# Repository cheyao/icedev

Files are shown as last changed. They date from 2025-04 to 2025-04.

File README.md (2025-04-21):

# Icedev

A ICE40 FPGA breakout board. With built in clock, voltage regs, ram and rom.

- 64 KiB of onboard flash
- 128 MiB of NOR flash
- 16 MHZ onboard Crystal
- 256 KiB of built-in RAM




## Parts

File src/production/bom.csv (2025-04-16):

Designator | Footprint | Quantity | Value | LCSC Part #
5V, C1, C10, C13, C15, C16, C18, C2, C21, C23, C3, C4, C8 | 0402 | 13 | 0.1u | C1525
C12, C14, C17, C19 | 0402 | 4 | 10u | C15525
C20, C5, C6, C7, C9 | 0402 | 5 | 10n | C15195
D1 | D_SOD-123 | 1 | Schottky Diode | C8598
D2, D4 | 0805 | 2 | G | C2297
D3 | 0603 | 1 | R | C2286
GND_3, R26 | 0805 | 2 | 5.1K | C27834
R19, R22, R23, R24, R25 | 0805 | 5 | 1K | C17513
R20, R21 | 0402 | 2 | 5.1K | C25905
R6, R7, R8, R9 | 0805 | 4 | 10K | C17414
U1 | QFN-48-1EP_7x7mm_P0.5mm_EP5.6x5.6mm | 1 | ICE40UP5K-SG48ITR | C2678152
U2 | SOT-223-3_TabPin2 | 1 | AMS1117-1.2 | C14529
U3 | SOT-223-3_TabPin2 | 1 | AMS1117-3.3 | C6186
U4 | SOIC-8_5.3x5.3mm_P1.27mm | 1 | W25Q128JVS | C97521
U5 | SOIC-8_3.9x4.9mm_P1.27mm | 1 | FM24C64B | C79988
U6 | SOT-23-6-routable | 1 | SRV05-4 | C85364
X1 | Oscillator_SMD_Abracon_ASE-4Pin_3.2x2.5mm | 1 | MPUOSC | C13738

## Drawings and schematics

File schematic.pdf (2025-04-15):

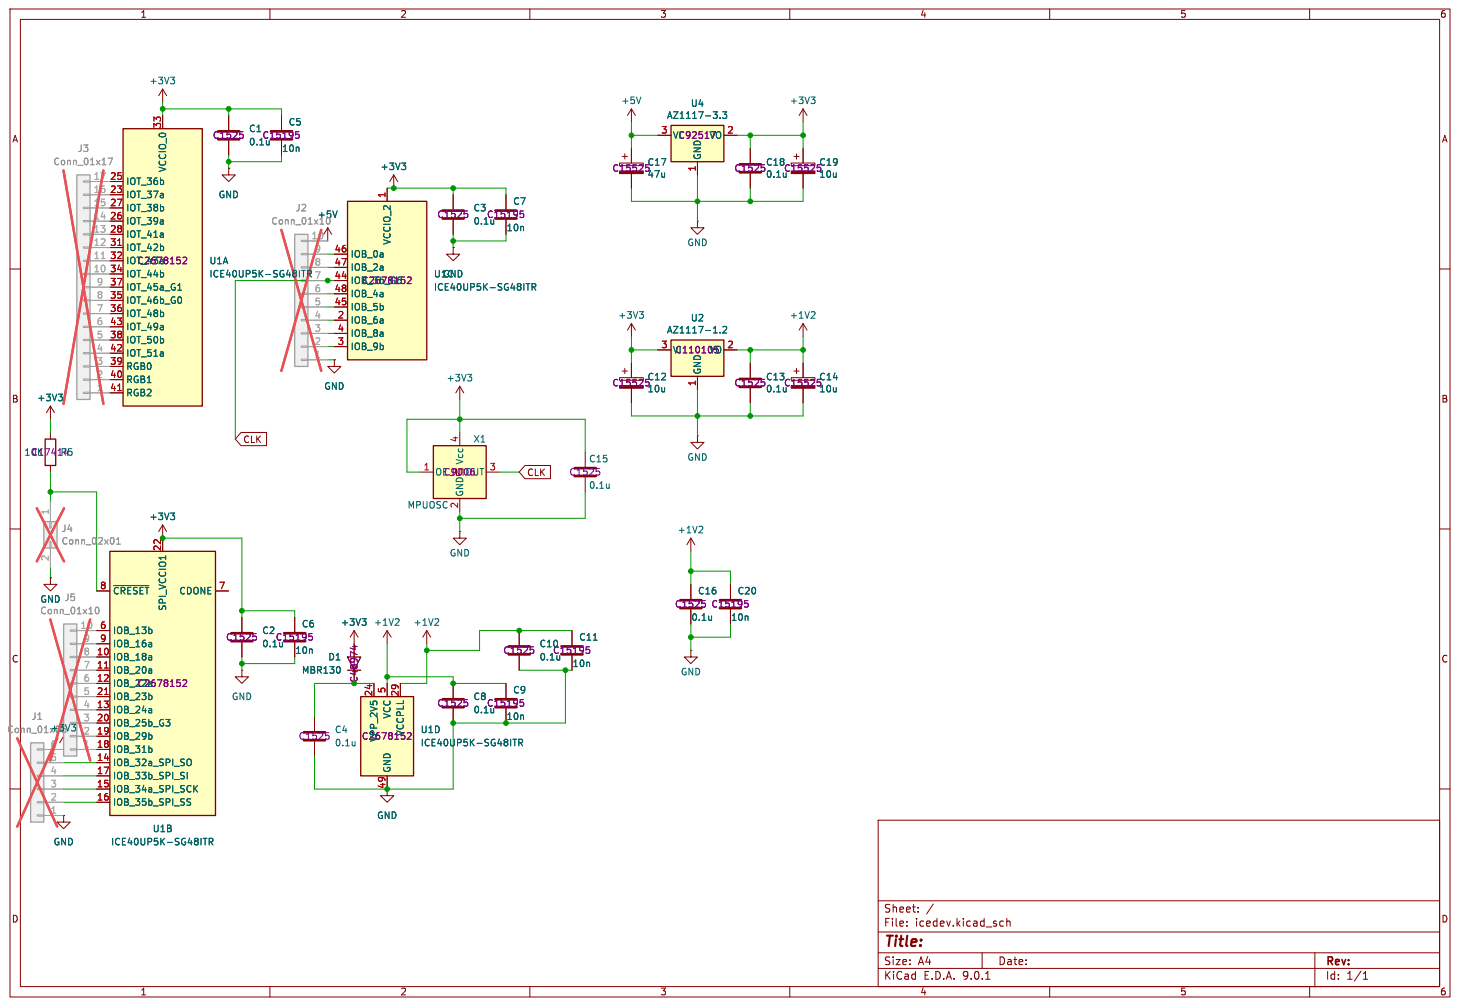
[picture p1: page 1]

Id: 1/1 Title: File: icedev.kicad_sch Sheet: /

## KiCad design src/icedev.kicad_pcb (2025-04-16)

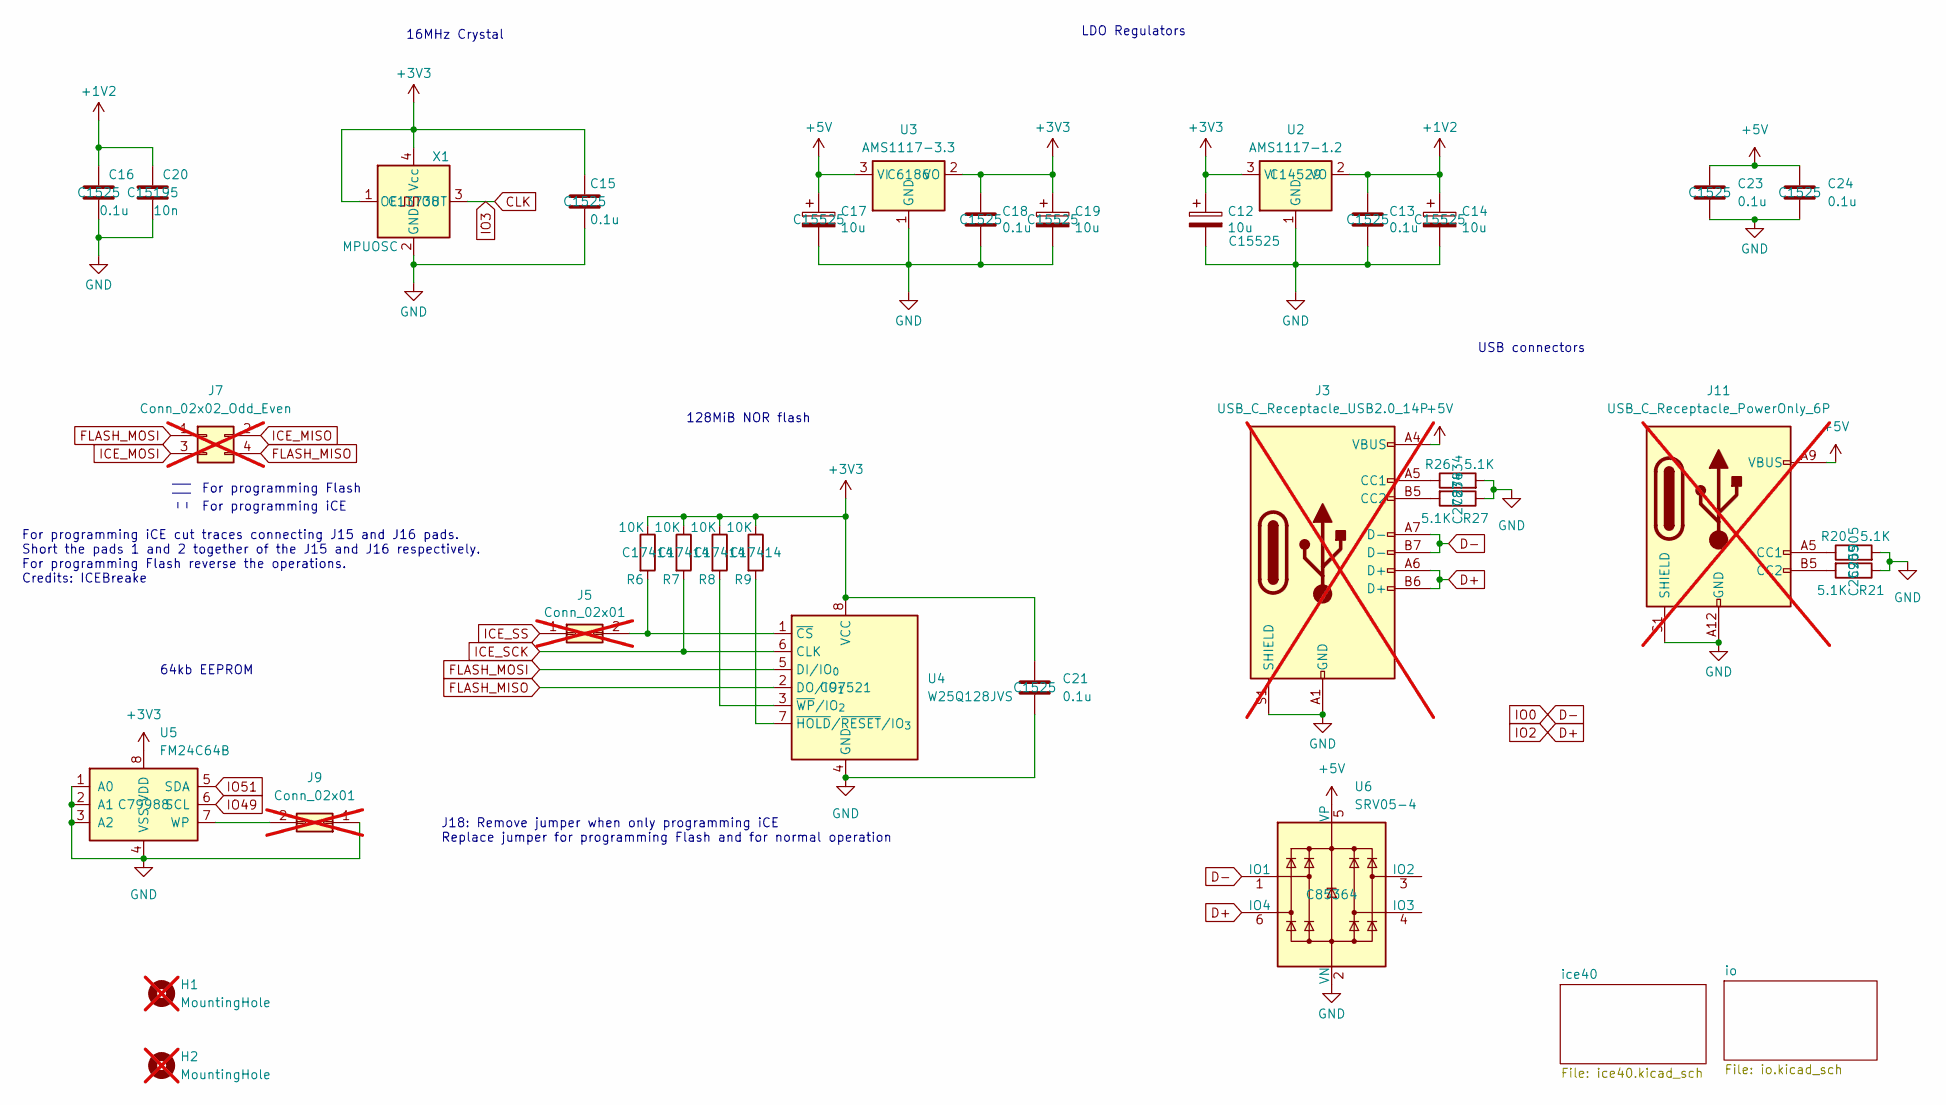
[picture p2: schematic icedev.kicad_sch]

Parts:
C12, C14, C17, C19: 10u; C_0402_1005Metric; JLCPCB Part # C15525
C13, C15, C16, C18, C21, C23, C24: 0.1u; C_0402_1005Metric; JLCPCB Part # C1525
C20: 10n; C_0402_1005Metric; JLCPCB Part # C15195
H1, H2: MountingHole; MountingHole_2.2mm_M2; not fitted
J3: USB_C_Receptacle_USB2.0_14P; USB_C_Receptacle_GCT_USB4105-xx-A_16P_TopMnt_Horizontal; not fitted
J5, J9: Conn_02x01; PinHeader_2x01_P2.54mm_Vertical; not fitted
J7: Conn_02x02_Odd_Even; PinSocket_2x02_P2.54mm_Vertical; not fitted
J11: USB_C_Receptacle_PowerOnly_6P; USB_C_Receptacle_GCT_USB4135-GF-A_6P_TopMnt_Horizontal; not fitted
R6, R7, R8, R9: 10K; R_0805_2012Metric; JLCPCB Part # C17414
R20, R21: 5.1K; R_0402_1005Metric; JLCPCB Part # C25905
R26, R27: 5.1K; R_0805_2012Metric; JLCPCB Part # C27834
U2: AMS1117-1.2; SOT-223-3_TabPin2; JLCPCB Part # C14529
U3: AMS1117-3.3; SOT-223-3_TabPin2; JLCPCB Part # C6186
U4: W25Q128JVS; SOIC-8_5.3x5.3mm_P1.27mm; JLCPCB Part # C97521
U5: FM24C64B; SOIC-8_3.9x4.9mm_P1.27mm; JLCPCB Part # C79988
U6: SRV05-4; SOT-23-6-routable; JLCPCB Part # C85364
X1: MPUOSC; Oscillator_SMD_Abracon_ASE-4Pin_3.2x2.5mm; JLCPCB Part # C13738

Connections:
+1V2: C13.1, C14.1, C16.1, C20.1, U2.2 (VO); also elsewhere on the board
+3V3: C12.1, C15.1, C18.1, C19.1, C21.1, R6.1, R7.1, R8.1, R9.1, U2.3 (VI), U3.2 (VO), U4.8 (VCC), U5.8 (VDD), X1.1 (OE), X1.4 (Vcc); also elsewhere on the board
+5V: C17.1, C23.1, C24.1, J3.A4 (VBUS), J3.A9 (VBUS), J3.B4 (VBUS), J3.B9 (VBUS), J11.A9 (VBUS), J11.B9 (VBUS), U3.3 (VI), U6.5 (VP); also elsewhere on the board
CLK: X1.3 (OUT); also elsewhere on the board
D+: J3.A6 (D+), J3.B6 (D+), U6.6 (IO4); also elsewhere on the board
D-: J3.A7 (D-), J3.B7 (D-), U6.1 (IO1); also elsewhere on the board
FLASH_MISO: J7.4, U4.2 (DO/IO_{1}); also elsewhere on the board
FLASH_MOSI: J7.1, U4.5 (DI/IO_{0}); also elsewhere on the board
GND: C12.2, C13.2, C14.2, C15.2, C16.2, C17.2, C18.2, C19.2, C20.2, C21.2, C23.2, C24.2, J3.A1 (GND), J3.A12 (GND), J3.B1 (GND), J3.B12 (GND), J3.S1 (SHIELD), J9.1, J11.A12 (GND), J11.B12 (GND), J11.S1 (SHIELD), R20.2, R21.1, R26.2, R27.1, U2.1 (GND), U3.1 (GND), U4.4 (GND), U5.1 (A0), U5.2 (A1), U5.3 (A2), U5.4 (VSS), U6.2 (VN), X1.2 (GND); also elsewhere on the board
ICE_MISO: J7.2; also elsewhere on the board
ICE_MOSI: J7.3; also elsewhere on the board
ICE_SCK: R7.2, U4.6 (CLK); also elsewhere on the board
ICE_SS: J5.1; also elsewhere on the board
IO49: U5.6 (SCL); also elsewhere on the board
IO51: U5.5 (SDA); also elsewhere on the board
unnamed: J3.A5 (CC1), R26.1
unnamed 52: J3.B5 (CC2), R27.2; also elsewhere on the board
unnamed: J5.2, R6.2, U4.1 (~CS)
unnamed: J9.2, U5.7 (WP)
unnamed: J11.A5 (CC1), R20.1
unnamed: J11.B5 (CC2), R21.2
unnamed: R9.2, U4.7 (~HOLD/~RESET/IO_{3})
unnamed: R8.2, U4.3 (~WP/IO_{2})

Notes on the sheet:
For programming Flash
J18: Remove jumper when only programming iCE Replace jumper for programming Flash and for normal operation
64kb EEPROM
16MHz Crystal
USB connectors
For programming iCE cut traces connecting J15 and J16 pads. Short the pads 1 and 2 together of the J15 and J16 respectively. For programming Flash reverse the operations. Credits: ICEBreake
128MiB NOR flash
LDO Regulators
For programming iCE

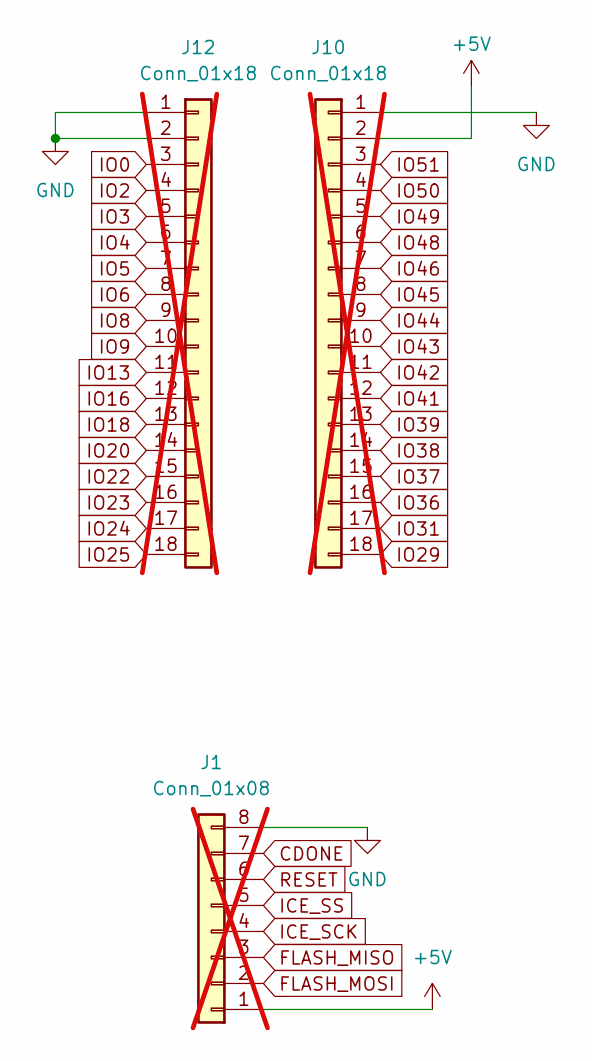
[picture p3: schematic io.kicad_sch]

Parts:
J1: Conn_01x08; PinSocket_1x08_P2.54mm_Vertical; not fitted
J10, J12: Conn_01x18; PinSocket_1x18_P2.54mm_Vertical; not fitted

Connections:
+5V: J1.1, J10.2; also elsewhere on the board
CDONE: J1.7; also elsewhere on the board
FLASH_MISO: J1.3; also elsewhere on the board
FLASH_MOSI: J1.2; also elsewhere on the board
GND: J1.8, J10.1, J12.1, J12.2; also elsewhere on the board
ICE_SCK: J1.4; also elsewhere on the board
ICE_SS: J1.5; also elsewhere on the board
RESET: J1.6; also elsewhere on the board

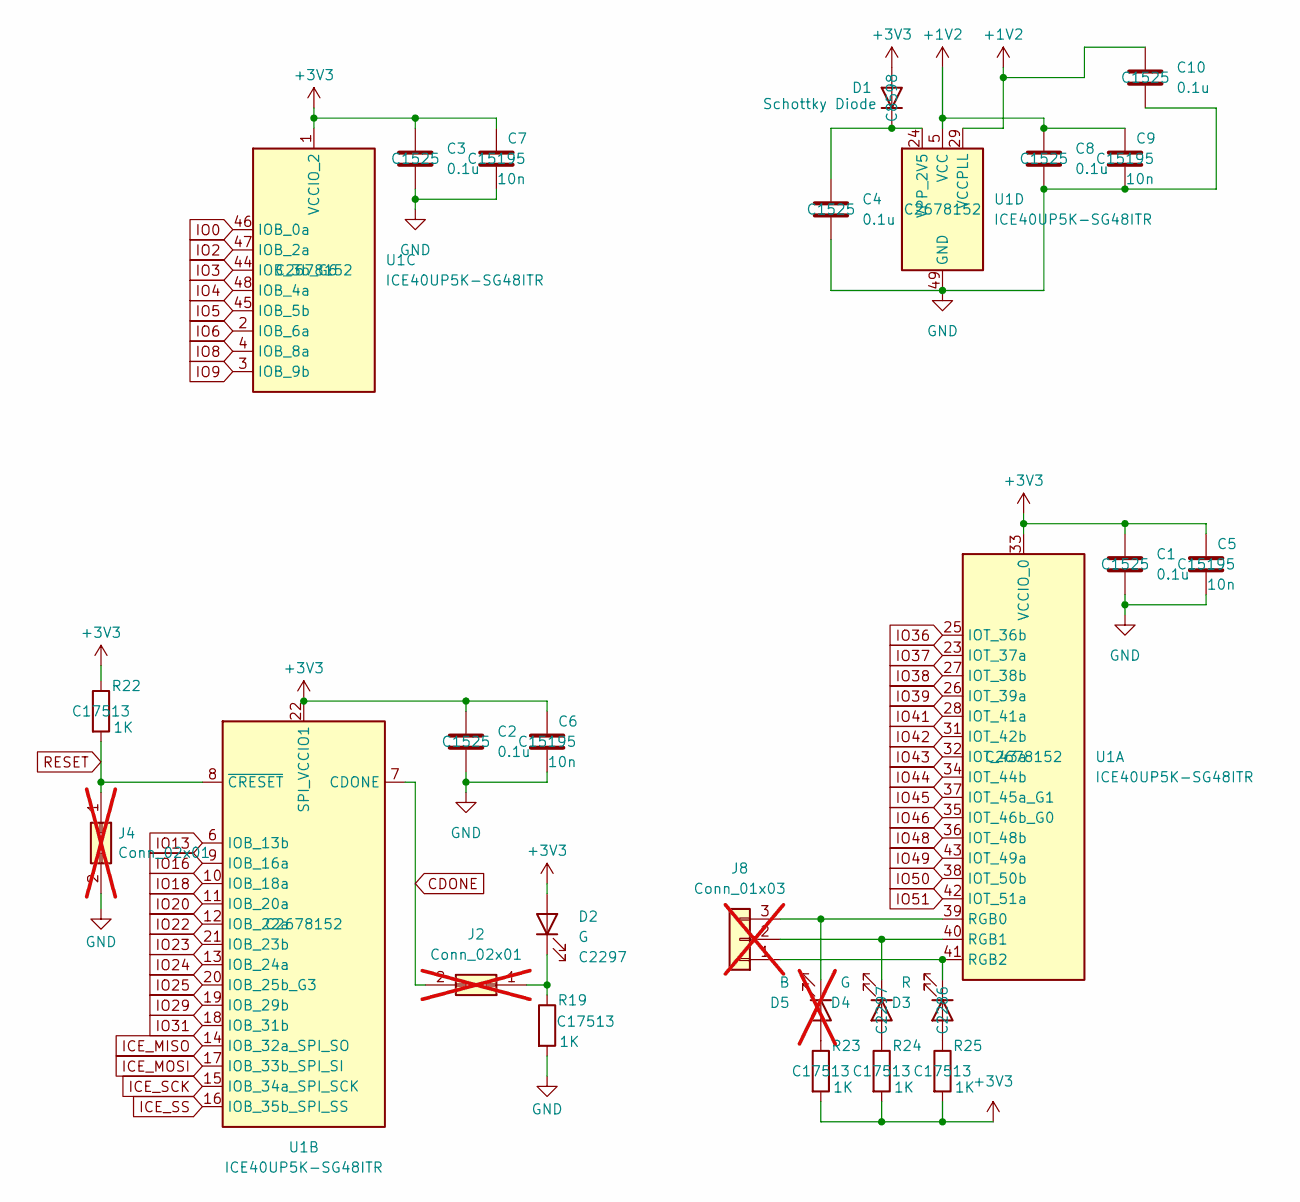
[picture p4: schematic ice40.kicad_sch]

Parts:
C1, C2, C3, C4, C8, C10: 0.1u; C_0402_1005Metric; JLCPCB Part # C1525
C5, C6, C7, C9: 10n; C_0402_1005Metric; JLCPCB Part # C15195
D1: Schottky Diode; D_SOD-123; JLCPCB Part # C8598
D2, D4: G; LED_0805_2012Metric; JLCPCB Part # C2297
D3: R; LED_0603_1608Metric; JLCPCB Part # C2286
D5: B; LED_0201_0603Metric_Pad0.64x0.40mm_HandSolder; not fitted
J2, J4: Conn_02x01; PinHeader_2x01_P2.54mm_Vertical; not fitted
J8: Conn_01x03; PinHeader_1x03_P2.54mm_Vertical; not fitted
R19, R22, R23, R24, R25: 1K; R_0805_2012Metric; JLCPCB Part # C17513
U1: ICE40UP5K-SG48ITR; QFN-48-1EP_7x7mm_P0.5mm_EP5.6x5.6mm; JLCPCB Part # C2678152

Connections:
+1V2: C8.1, C9.1, C10.1, U1.5 (VCC), U1.29 (VCCPLL), U1.30 (VCC); also elsewhere on the board
+3V3: C1.1, C2.1, C3.1, C5.1, C6.1, C7.1, D1.2 (A), D2.2 (A), R22.1, R23.2, R24.2, R25.2, U1.1 (VCCIO_2), U1.22 (SPI_VCCIO1), U1.33 (VCCIO_0); also elsewhere on the board
CDONE: J2.2, U1.7 (CDONE); also elsewhere on the board
CLK: U1.44 (IOB_3b_G6); also elsewhere on the board
D+: U1.47 (IOB_2a); also elsewhere on the board
D-: U1.46 (IOB_0a); also elsewhere on the board
GND: C1.2, C2.2, C3.2, C4.2, C5.2, C6.2, C7.2, C8.2, C9.2, C10.2, J4.2, R19.2, U1.49 (GND); also elsewhere on the board
ICE_MISO: U1.14 (IOB_32a_SPI_SO); also elsewhere on the board
ICE_MOSI: U1.17 (IOB_33b_SPI_SI); also elsewhere on the board
ICE_SCK: U1.15 (IOB_34a_SPI_SCK); also elsewhere on the board
ICE_SS: U1.16 (IOB_35b_SPI_SS); also elsewhere on the board
IO4: U1.48 (IOB_4a); also elsewhere on the board
IO5: U1.45 (IOB_5b); also elsewhere on the board
IO6: U1.2 (IOB_6a); also elsewhere on the board
IO8: U1.4 (IOB_8a); also elsewhere on the board
IO9: U1.3 (IOB_9b); also elsewhere on the board
IO13: U1.6 (IOB_13b); also elsewhere on the board
IO16: U1.9 (IOB_16a); also elsewhere on the board
IO18: U1.10 (IOB_18a); also elsewhere on the board
IO20: U1.11 (IOB_20a); also elsewhere on the board
IO22: U1.12 (IOB_22a); also elsewhere on the board
IO23: U1.21 (IOB_23b); also elsewhere on the board
IO24: U1.13 (IOB_24a); also elsewhere on the board
IO25: U1.20 (IOB_25b_G3); also elsewhere on the board
IO29: U1.19 (IOB_29b); also elsewhere on the board
IO31: U1.18 (IOB_31b); also elsewhere on the board
IO36: U1.25 (IOT_36b); also elsewhere on the board
IO37: U1.23 (IOT_37a); also elsewhere on the board
IO38: U1.27 (IOT_38b); also elsewhere on the board
IO39: U1.26 (IOT_39a); also elsewhere on the board
IO41: U1.28 (IOT_41a); also elsewhere on the board
IO42: U1.31 (IOT_42b); also elsewhere on the board
IO43: U1.32 (IOT_43a); also elsewhere on the board
IO44: U1.34 (IOT_44b); also elsewhere on the board
IO45: U1.37 (IOT_45a_G1); also elsewhere on the board
IO46: U1.35 (IOT_46b_G0); also elsewhere on the board
IO48: U1.36 (IOT_48b); also elsewhere on the board
IO49: U1.43 (IOT_49a); also elsewhere on the board
IO50: U1.38 (IOT_50b); also elsewhere on the board
IO51: U1.42 (IOT_51a); also elsewhere on the board
unnamed: C4.1, D1.1 (K), U1.24 (VPP_2V5)
unnamed: D2.1 (K), J2.1, R19.1
unnamed: D3.2 (A), R25.1
unnamed: D3.1 (K), J8.1, U1.41 (RGB2)
unnamed: D4.2 (A), R24.1
unnamed: D4.1 (K), J8.2, U1.40 (RGB1)
unnamed: D5.2 (A), R23.1
unnamed: D5.1 (K), J8.3, U1.39 (RGB0)
RESET: J4.1, R22.2, U1.8 (~CRESET); also elsewhere on the board

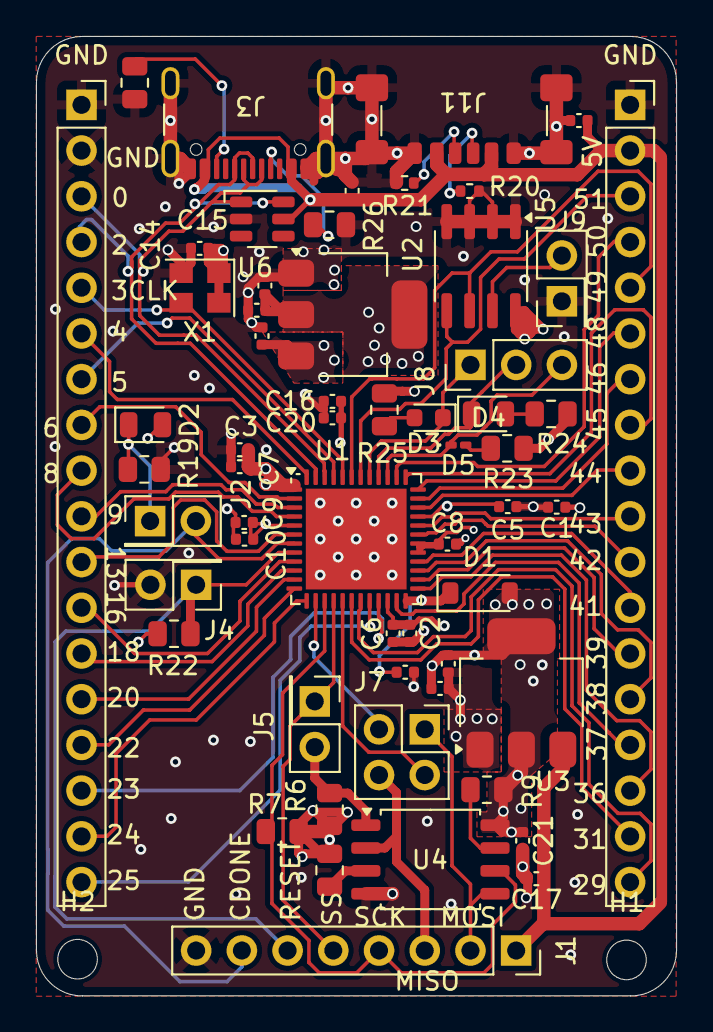
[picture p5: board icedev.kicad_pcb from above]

Board: 4 copper layers, 35.6 x 53.3 mm, 60 parts (0 on the bottom side), 60 nets.

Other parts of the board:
5V: 0.1u; C_0402_1005Metric
GND: Conn_01x18; PinSocket_1x18_P2.54mm_Vertical
GND#2: 5.1K; R_0805_2012Metric
GND#3: Conn_01x18; PinSocket_1x18_P2.54mm_Vertical

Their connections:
+5V: 5V.1, GND#3.2; also elsewhere on the board
CLK: GND.5; also elsewhere on the board
D+: GND.4; also elsewhere on the board
D-: GND.3; also elsewhere on the board
GND: 5V.2, GND.1, GND.2, GND#2.1, GND#3.1; also elsewhere on the board
IO4: GND.6; also elsewhere on the board
IO5: GND.7; also elsewhere on the board
IO6: GND.8; also elsewhere on the board
IO8: GND.9; also elsewhere on the board
IO9: GND.10; also elsewhere on the board
IO13: GND.11; also elsewhere on the board
IO16: GND.12; also elsewhere on the board
IO18: GND.13; also elsewhere on the board
IO20: GND.14; also elsewhere on the board
IO22: GND.15; also elsewhere on the board
IO23: GND.16; also elsewhere on the board
IO24: GND.17; also elsewhere on the board
IO25: GND.18; also elsewhere on the board
IO29: GND#3.18; also elsewhere on the board
IO31: GND#3.17; also elsewhere on the board
IO36: GND#3.16; also elsewhere on the board
IO37: GND#3.15; also elsewhere on the board
IO38: GND#3.14; also elsewhere on the board
IO39: GND#3.13; also elsewhere on the board
IO41: GND#3.12; also elsewhere on the board
IO42: GND#3.11; also elsewhere on the board
IO43: GND#3.10; also elsewhere on the board
IO44: GND#3.9; also elsewhere on the board
IO45: GND#3.8; also elsewhere on the board
IO46: GND#3.7; also elsewhere on the board
IO48: GND#3.6; also elsewhere on the board
IO49: GND#3.5; also elsewhere on the board
IO50: GND#3.4; also elsewhere on the board
IO51: GND#3.3; also elsewhere on the board
unnamed 52: GND#2.2; also elsewhere on the board

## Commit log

2025-04-16 Rev 2
    [bom.csv, designators.csv, icedev.kicad_pcb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]
2025-04-16 Some more improvements and readme images
    [bom.csv, designators.csv, ice40.kicad_sch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]
2025-04-16 Off to prod!
    [bom.csv, designators.csv, ice40.kicad_sch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]
